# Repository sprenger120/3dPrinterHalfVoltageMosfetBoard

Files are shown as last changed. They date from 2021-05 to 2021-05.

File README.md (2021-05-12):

# 3D Printer Half Voltage MOSFET Board
Makes 12V Heaters (Bed + Extruder) compatible with 24V by plugging in between your 3D Printer's motherboard and your heating elements. 
The board contains **overheat protection** and will leave the heaters off regardless of what the 3D printer wants. When your printer is configured correctly a thermal runaway error should stop the machine.
The firmware also allows you to finely control how much voltage you want to send to your heaters if the 50% reduction isn't enough or you want to boost performance slightly.

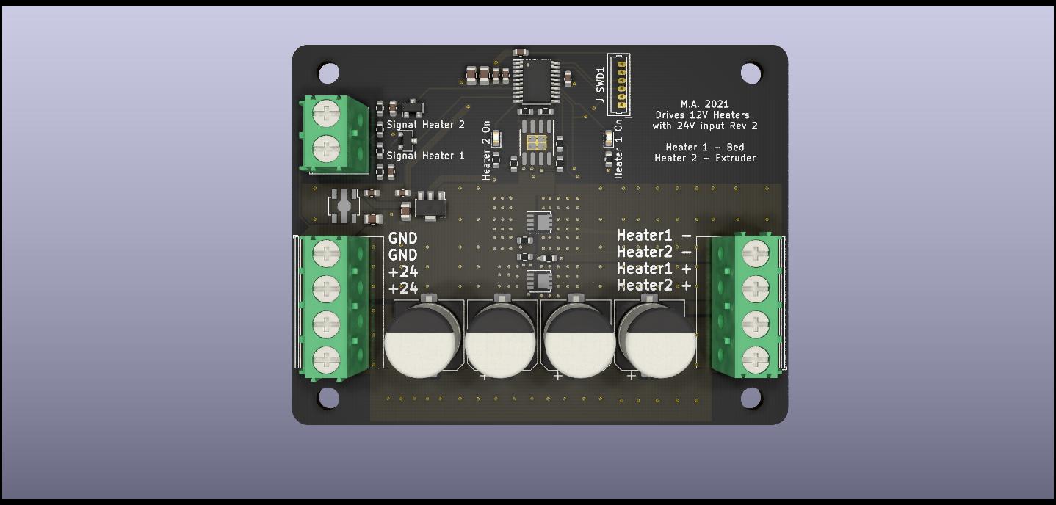
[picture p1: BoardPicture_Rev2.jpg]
PCB image


### Making one

This project is mostly built from stuff I had laying around so make changes according to what you had laying around. *Capacitors with a higher voltage but the same farads rating are always compatible!*  

You can find the PCB's gerber files in fab/.

- 1x 10uF 36V MLCC , 0805 (imperial) 
- 3x 2.2uF 16V MLCC, 0603 (imperial) 
- 3x 1uF 36V MLCC, 0805 (imperial) 
- 7x 100nF 16V MLCC, 0603 (imperial) 
- 4x 100uF 35V Al-Poly Capacitor, 10x12mm
- 2x Green LED, 0603 (imperial)
- 1x ESDCAN01-2BLY TVS diode (optional if you like to live "dangerously")
- 2x Phoenix 1987740 Screw Terminal 32A (select something equivalent, these have a wierd orientation)
- 1x Phoenix 1729018 Screw Terminal 10A (or just solder wires, this is for signal only)
- 2x Vishay SiSA88DN N-Ch Enh. MOSFET
- 4x 20k Ohm Resistor, 0603 (imperial)
- 2x 300 Ohm Resistor, 0603 (imperial)
- 3x 10k Ohm Resistor, 0603 (imperial)
- 2x 10 Ohm Resistor, 0603 (imperial)
- 2x 100k Ohm Resistor, 0603 (imperial)
- 1x 10k Ohm NTC Thermistor, 0603 (imperial) (Panasonic ERT-J1VG103JA or equivalent)
- 1x STM32L011F3P Microcontroller
- 1x MCP1703A-3302 3.3V fixed linear regulator
- 1x XC6702-3.3 12V fixed linear regulator
- 1x MIC4126 MOSFET driver

Get a cheap STLINK off of ebay and hook up the pins of the J_SWD connector to it.

**todo swd port pinout**, **todo flash manual**

### Wiring 

- Connect your power supplies' 24V directly to one of the GND, 24V pairs on the left side. Connect the other GND, 24V pair to your motherboard. They are internally bridged. You may use thinner wiring for this connection as your 3D Printer's motherboard now consumes way less power. 
- Connect your heated bed to Heater1+ and Heater1- and your extruder to Heater 2+ and -. Polarity doesn't matter as heaters are just resistors. 
- Connect the **negative** side of your 3D printer's heated bed power output to "Signal Heater 1". Do the same for the extruder output and "Signal Heater 2". 

You have to connect the "Signal Heater" pins to the negative side as virtually all 3D printer motherboards don't switch the plus side but rather switch the negative side. If you would connect the the "Signal Heater" pins to the positive side the board the heaters will stay off permanently.

**todo rev. 1 testing**

### Revisions

- Rev. 2
   - Secured "Signal Heater" inputs against accidental 24V connection
- Rev. 1 (Initial release)

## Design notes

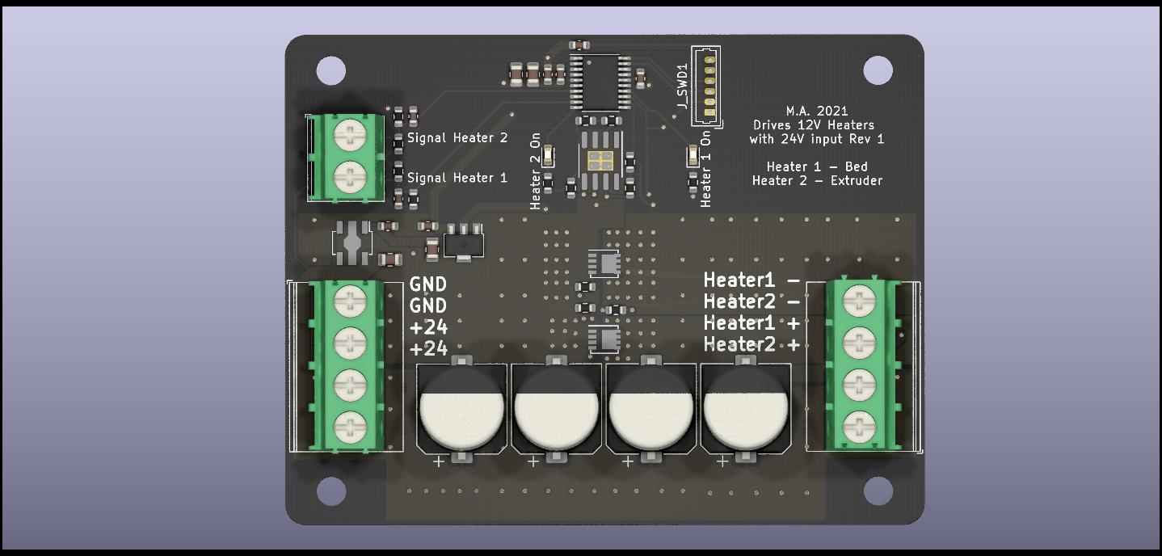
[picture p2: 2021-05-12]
BoardPicture_Rev1.jpg

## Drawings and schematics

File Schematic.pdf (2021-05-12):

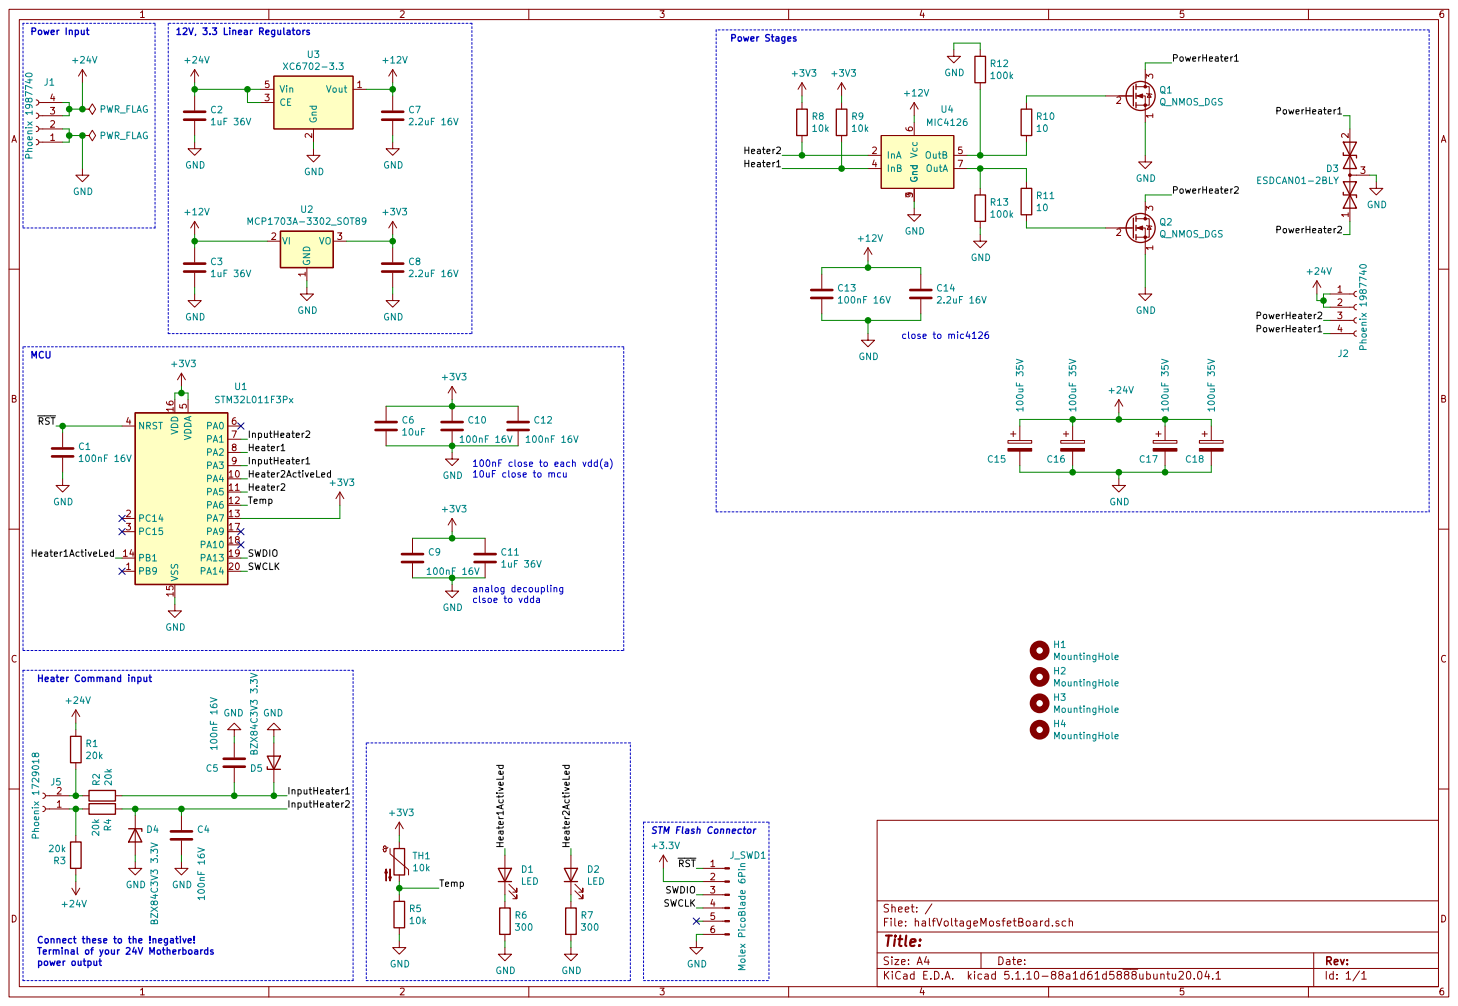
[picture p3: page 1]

Power Stages Power Input

GND
Heater Command input MCU

1 VI 2 VO 3 U2 MCP1703A-3302_SOT89 NRST 4 PA0 6 PA1 7 PA10 18 PA13 19 PA14 20 PA2 8 PA3 9 PA4 10 PA5 11 PA6 12 PA7 13 PA9 17 PB1 14 PB9 1 PC14 2 PC15 3 VDD 16 VDDA

100nF close to each vdd(a) 10uF close to mcu

File: halfVoltageMosfetBoard.sch Sheet: / R6

Connect these to the !negative!
Terminal of your 24V Motherboards power output

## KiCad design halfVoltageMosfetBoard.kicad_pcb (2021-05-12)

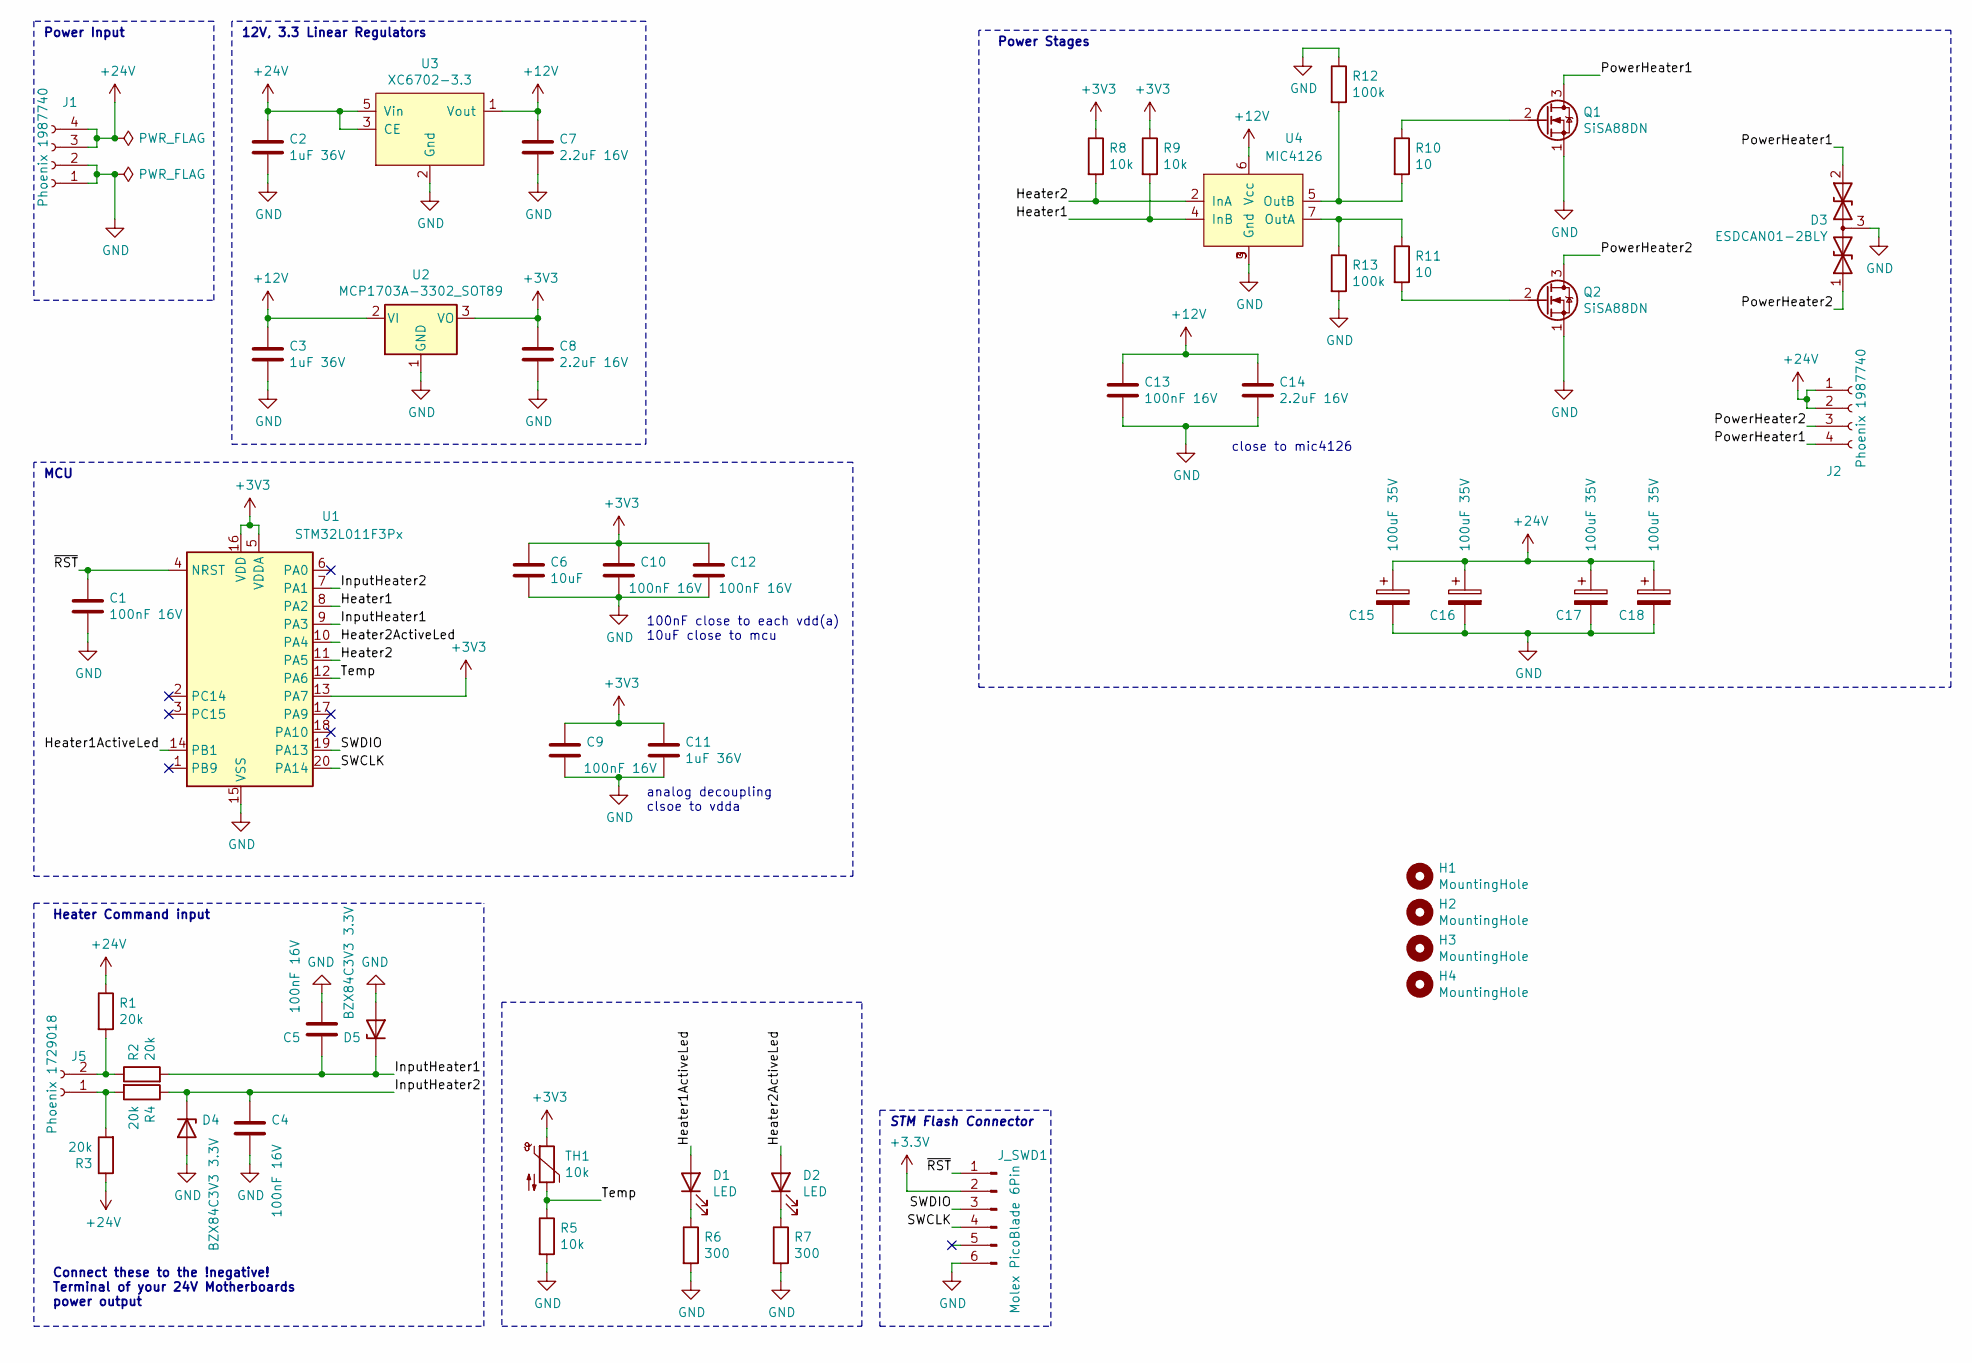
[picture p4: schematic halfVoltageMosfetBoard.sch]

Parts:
C1, C4, C5, C9, C10, C12, C13: 100nF 16V; C_0603_1608Metric
C2, C3, C11: 1uF 36V; C_0805_2012Metric
C6: 10uF; C_0805_2012Metric
C7, C8, C14: 2.2uF 16V; C_0603_1608Metric
C15, C16, C17, C18: 100uF 35V; CP_Elec_10x12.5
D1, D2: LED; LED_0603_1608Metric
D3: ESDCAN01-2BLY; SOT-23
D4, D5: BZX84C3V3 3.3V; D_SOT-23_ANK
H1, H2, H3, H4: MountingHole; MountingHole_3.5mm
J1, J2: Phoenix 1987740; TerminalBlock_Phoenix_PT-1,5-4-5.0-H_1x04_P5.00mm_Horizontal
J5: Phoenix 1729018; TerminalBlock_Phoenix_PT-1,5-2-5.0-H_1x02_P5.00mm_Horizontal
J_SWD1: Molex PicoBlade 6Pin; Molex_PicoBlade_53047-0610_1x06_P1.25mm_Vertical
Q1, Q2: SiSA88DN; Vishay_PowerPAK_1212-8_Single
R1, R2, R3, R4: 20k; R_0603_1608Metric
R5, R8, R9: 10k; R_0603_1608Metric
R6, R7: 300; R_0603_1608Metric
R10, R11: 10; R_0603_1608Metric
R12, R13: 100k; R_0603_1608Metric
TH1: 10k; R_0603_1608Metric
U1: STM32L011F3Px; TSSOP-20_4.4x6.5mm_P0.65mm
U2: MCP1703A-3302_SOT89; SOT-89-3
U3: XC6702-3.3; SOT-89-5
U4: MIC4126; SOIC-8-1EP_3.9x4.9mm_P1.27mm_EP2.29x3mm_ThermalVias

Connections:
+12V: C3.1, C7.1, C13.1, C14.1, U2.2 (VI), U3.1 (Vout), U4.6 (Vcc)
+24V: C2.1, C15.1, C16.1, C17.1, C18.1, J1.3, J1.4, J2.1, J2.2, R1.1, R3.1, U3.3 (CE), U3.5 (Vin)
/Heater1: R9.2, U1.8 (PA2), U4.4 (InB)
/Heater1ActiveLed: D1.2 (A), U1.14 (PB1)
/Heater2: R8.2, U1.11 (PA5), U4.2 (InA)
/Heater2ActiveLed: D2.2 (A), U1.10 (PA4)
/InputHeater1: C5.1, D5.1 (K), R2.2, U1.9 (PA3)
/InputHeater2: C4.1, D4.1 (K), R4.1, U1.7 (PA1)
/PowerHeater1: D3.2 (A2), J2.4, Q1.3 (D)
/PowerHeater2: D3.1 (A1), J2.3, Q2.3 (D)
/SWCLK: J_SWD1.4, U1.20 (PA14)
/SWDIO: J_SWD1.3, U1.19 (PA13)
/Temp: R5.1, TH1.2, U1.12 (PA6)
/~RST: C1.1, J_SWD1.1, U1.4 (NRST)
GND: C1.2, C2.2, C3.2, C4.2, C5.2, C6.2, C7.2, C8.2, C9.2, C10.2, C11.2, C12.2, C13.2, C14.2, C15.2, C16.2, C17.2, C18.2, D3.3 (common), D4.2 (A), D5.2 (A), J1.1, J1.2, J_SWD1.6, Q1.1 (S), Q2.1 (S), R5.2, R6.2, R7.2, R12.1, R13.2, U1.15 (VSS), U2.1 (GND), U3.2 (Gnd), U4.3 (Gnd), U4.9 (Gnd)
unnamed: D1.1 (K), R6.1
unnamed: D2.1 (K), R7.1
unnamed: J5.1, R3.2, R4.2
unnamed: J5.2, R1.2, R2.1
unnamed: Q1.2 (G), R10.1
unnamed: Q2.2 (G), R11.2
unnamed: R10.2, R12.2, U4.5 (OutB)
unnamed: R11.1, R13.1, U4.7 (OutA)

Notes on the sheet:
close to mic4126
STM Flash Connector
Power Input
12V, 3.3 Linear Regulators
Power Stages
analog decoupling clsoe to vdda
100nF close to each vdd(a) 10uF close to mcu
MCU
Connect these to the !negative! Terminal of your 24V Motherboards power output
Heater Command input

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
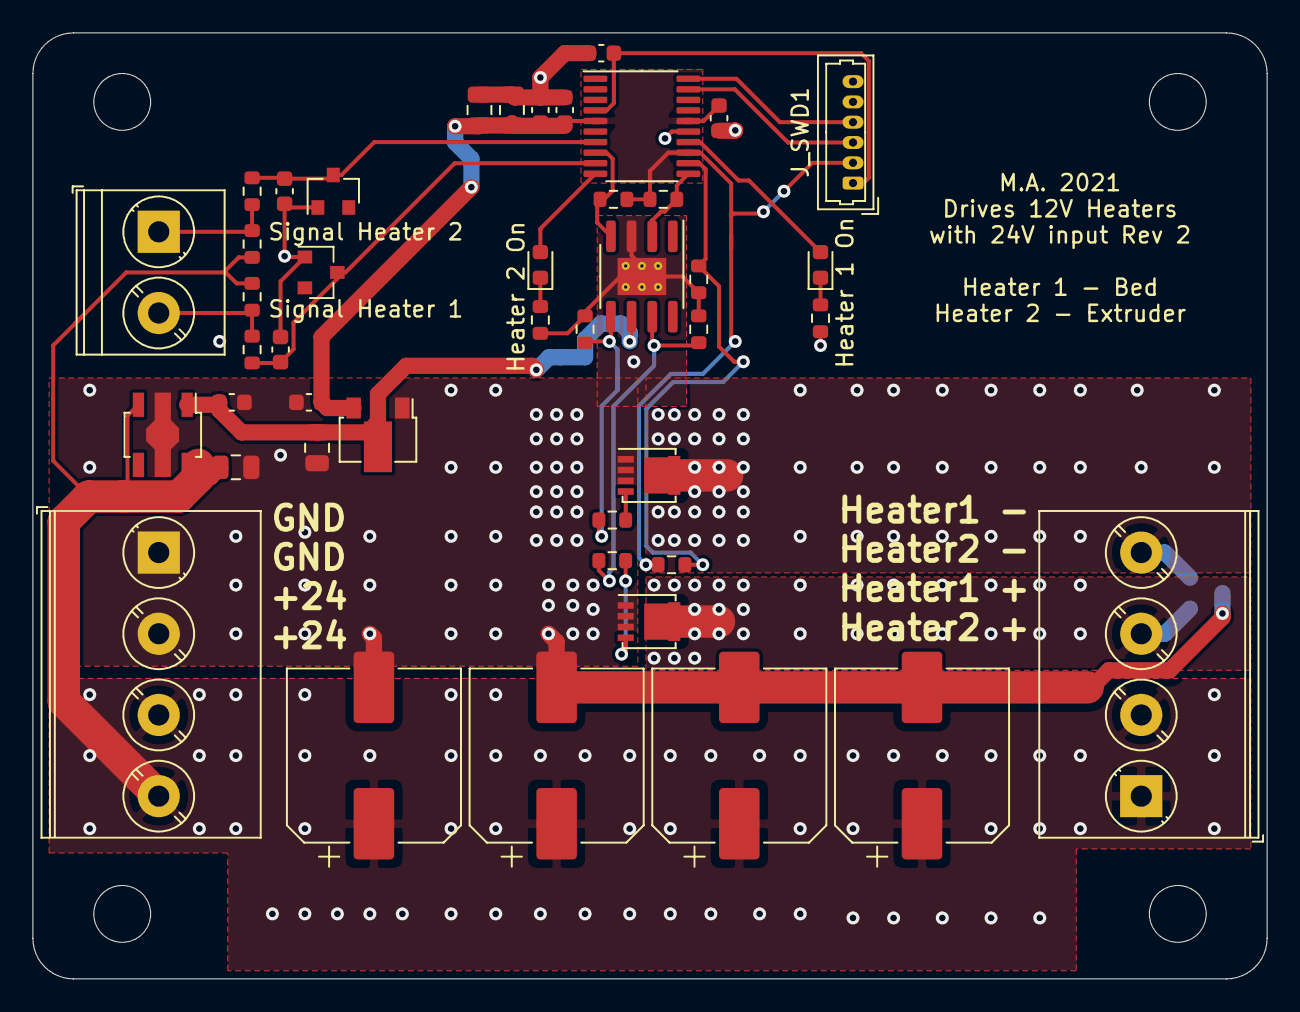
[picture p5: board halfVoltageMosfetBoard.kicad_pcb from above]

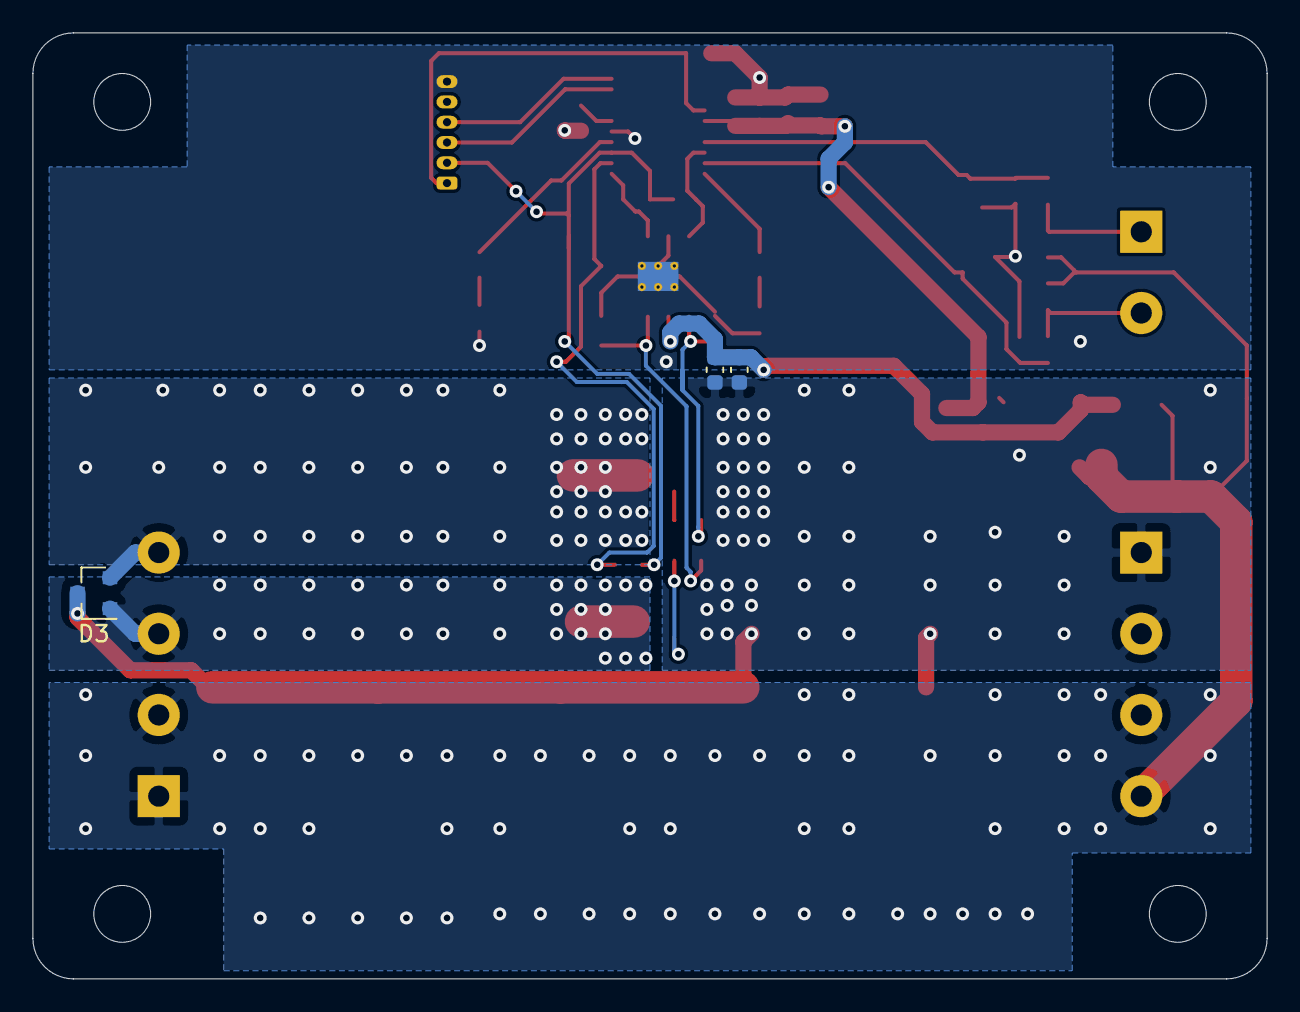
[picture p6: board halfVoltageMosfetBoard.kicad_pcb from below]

Board: 2 copper layers, 76.0 x 58.2 mm, 51 parts (3 on the bottom side), 24 nets.

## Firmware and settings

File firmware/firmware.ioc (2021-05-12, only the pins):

Mcu.UserName=STM32L011F3Px
PA13.Signal=SYS_SWDIO
PA14.Signal=SYS_SWCLK
PA2.Signal=S_TIM21_CH1
PA5.Signal=S_TIM2_CH1
PA6.Signal=ADC_IN6

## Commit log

2021-05-12 finished schematic
    [halfVoltageMosfetBoard.kicad_pcb, halfVoltageMosfetBoard.sch]
2021-05-12 finished layout rev A
    [halfVoltageMosfetBoard-B_Cu.gbr, halfVoltageMosfetBoard-B_Mask.gbr, halfVoltageMosfetBoard-B_Paste.gbr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]
2021-05-12 Revision 2 changes see readme Added text to readme Exported schematic
    [halfVoltageMosfetBoard-B_Cu.gbr, halfVoltageMosfetBoard-B_Mask.gbr, halfVoltageMosfetBoard-B_Paste.gbr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]
2021-05-12 note about gerber files
